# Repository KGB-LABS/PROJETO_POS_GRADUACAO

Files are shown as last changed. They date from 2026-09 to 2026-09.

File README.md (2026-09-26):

# Sistema IoT de Monitoramento Residencial Inteligente com ESP32

## 📌 Concepção e Objetivo do Projeto
Este projeto consiste no desenvolvimento de um sistema embarcado de automação, monitoramento climático e segurança perimetral residencial, fundamentado nas premissas da **Internet das Coisas (IoT)**. Desenvolvido como protótipo funcional para fins acadêmicos de Pós-Graduação, o ecossistema utiliza a placa de desenvolvimento **ESP32 DevKit** como unidade central de processamento para gerenciar, de forma assíncrona, sensores meteorológicos, termo-higrométricos e de intrusão física.

O principal objetivo técnico é garantir a integridade dos dados locais, transmitindo-os de maneira otimizada e segura para plataformas em nuvem, permitindo que o usuário interaja e receba alertas críticos em tempo real, independentemente de sua localização geográfica.

---

## 🏗️ Modelagem e Arquitetura do Sistema 

O fluxo de dados do ecossistema foi estruturado sob o conceito de **comunicação bidirecional**, segregado em três camadas fundamentais (Percepção, Transporte e Aplicação):

```text
  [ CAMADA DE PERCEPÇÃO ]            [ CAMADA DE TRANSPORTE ]            [ CAMADA DE APLICAÇÃO ]
  ┌──────────────────────┐                                               ┌──────────────────────┐
  │  Sensor MH-RD        │ ──┐                                        ┌> │  HiveMQ Cloud (MQTT) │
  │  (Chuva / Digital)   │   │                                        │  └──────────────────────┘
  ├──────────────────────┤   │    ┌─────────────────────────────┐     │
  │  Sensor Magnético    │   ├──> │        ESP32 DevKit         │ ────┤
  │  (Porta / Reed)      │   │    │ - Gestão por Edge Trigger   │     │
  ├──────────────────────┤   │    │ - Portal Cativo Local       │     │  ┌──────────────────────┐
  │  Sensor DHT11        │ ──┘    └─────────────────────────────┘     └> │  Telegram Bot API    │
  │  (Temp. / Umidade)   │                                               └──────────────────────┘
  └──────────────────────┘
```

### 1. Monitoramento Ativo (Modo Publisher / Transmissão Assíncrona)
O sistema opera baseado no princípio de **Gatilho por Borda (Edge Triggering)**. Os sensores de perímetro e meteorológicos são monitorados continuamente na camada de hardware. No entanto, o envio de dados para a nuvem só ocorre quando há uma **transição real de estado físico** (ex: o início/fim de uma chuva ou a abertura/fechamento de uma porta). Essa abordagem de engenharia de software elimina o tráfego de rede redundante, reduzindo o consumo de banda e poupando ciclos de processamento da MCU.

### 2. Requisições Sob Demanda (Modo Subscriber / Interação Remota)
A camada de aplicação permite que o usuário faça consultas ativas ao sistema. Ao enviar um comando de texto estruturado pela interface do usuário, a solicitação é transportada até o microcontrolador, que realiza a leitura imediata dos parâmetros ambientais de temperatura e umidade, retornando as métricas instantaneamente.

---

## 📸 Demonstração Visual do Protótipo

Abaixo está disposto o registro visual da das conexões de Hardware para cada unidade de processamento do ecossistema IoT residencial.

<p align="center">
 
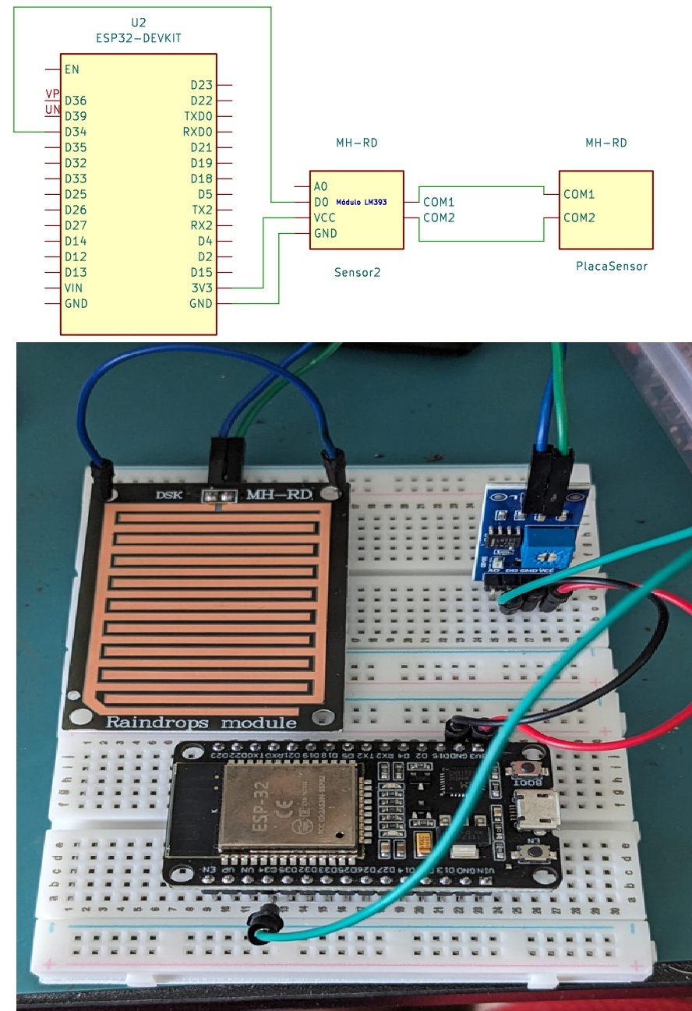
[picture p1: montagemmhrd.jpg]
Placa de Desenvolvimento ESP32 DevKit + Módulo MH-RD
  
  <br>
  <em>Figura 1: Unidade de Processamento Central baseada na placa de desenvolvimento ESP32 DevKit + Módulo MH-RD (CHUVA).</em>
</p>

<p align="center">

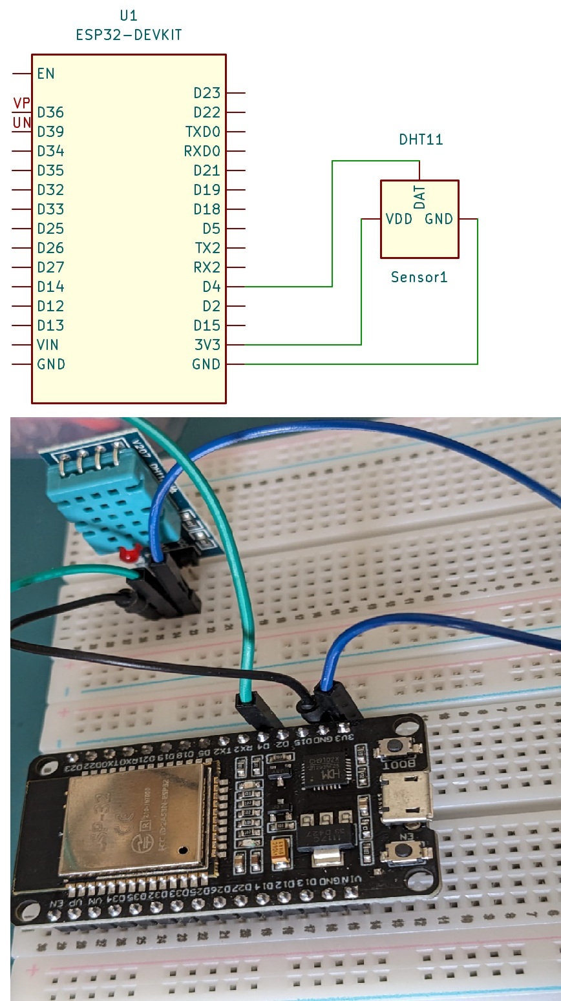
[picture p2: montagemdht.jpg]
Placa de Desenvolvimento ESP32 DevKit + Módulo DHT11
  
  <br>
  <em>Figura 2: Unidade de Processamento Central baseada na placa de desenvolvimento ESP32 DevKit + DHT11 (TEMP).</em>
</p>

<p align="center">

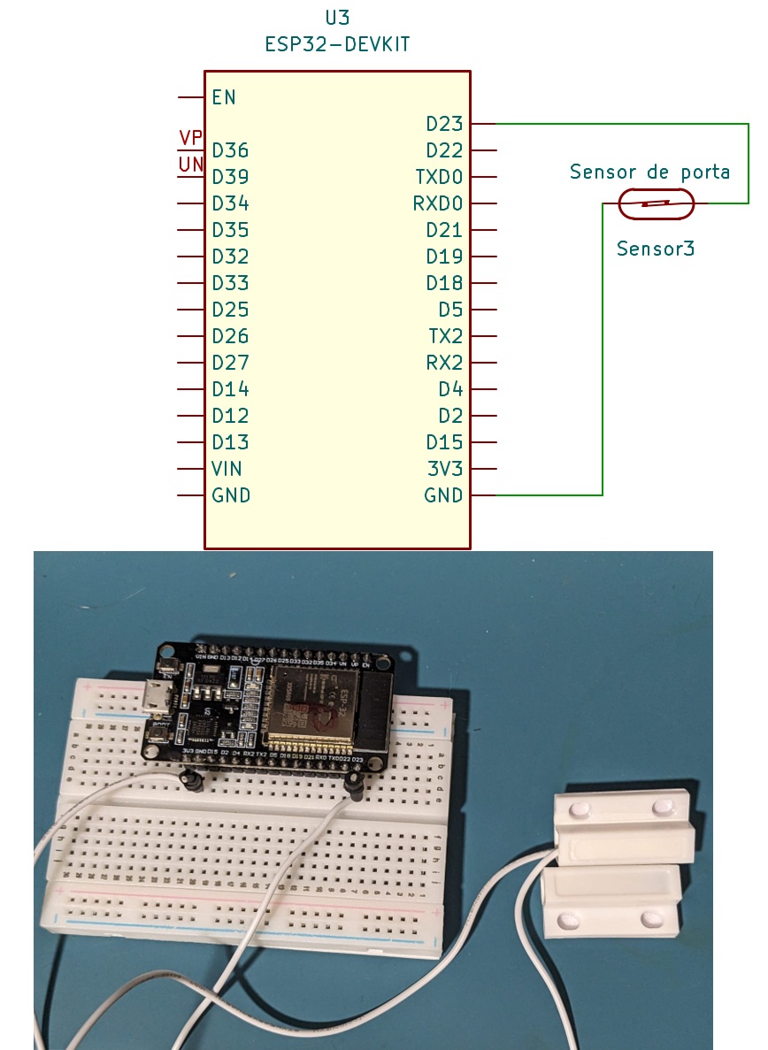
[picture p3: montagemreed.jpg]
Placa de Desenvolvimento ESP32 DevKit + Módulo Reed
  
  <br>
  <em>Figura 3: Unidade de Processamento Central baseada na placa de desenvolvimento ESP32 DevKit + Módulo Reed Sensor de Porta.</em>
</p>

---

## 🛠️ Especificações Técnicas de Hardware

A seleção dos componentes obedeceu a critérios rígidos de estabilidade de sinal, isolamento de ruídos eletromagnéticos e compatibilidade nativa de níveis lógicos em **3.3V DC**:

*   **Unidade de Processamento Central (MCU):** Placa de Desenvolvimento **ESP32 DevKit**. Baseada no SoC Xtensa Dual-Core de 32 bits com clock de até 240 MHz. Integra regulador de tensão onboard para conversão de alimentação USB/Externa para os níveis de barramento internos, além de transceptores para redes sem fio (Wi-Fi 802.11 b/g/n) e subsistema de memória não-volátil (NVS).
<p align="center">
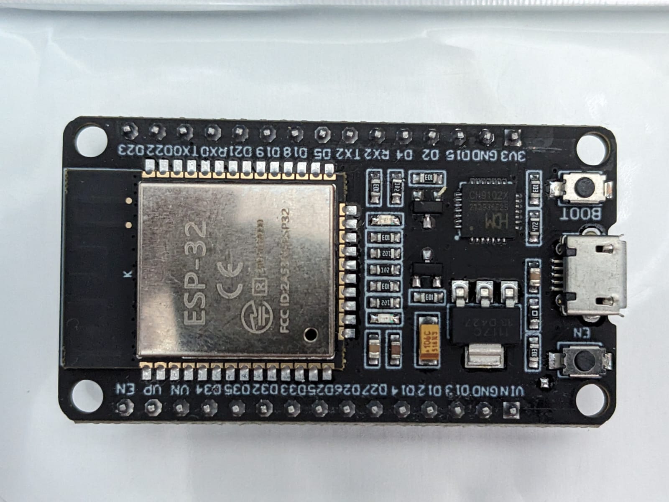
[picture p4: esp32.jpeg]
Esp32 Devkit
  
  <br>
  <em>Figura 4: MCU tipo Esp32 DEVKIT responsável pelo processamento.</em>
</p>

*   **Módulo Sensor Pluviométrico (MH-RD):** Composto por uma grade condutora exposta à precipitação e um circuito integrador baseado no comparador de tensão **LM393**. O módulo filtra as variações resistivas provocadas pela condutividade da água e entrega um sinal digital estabilizado.

<p align="center">
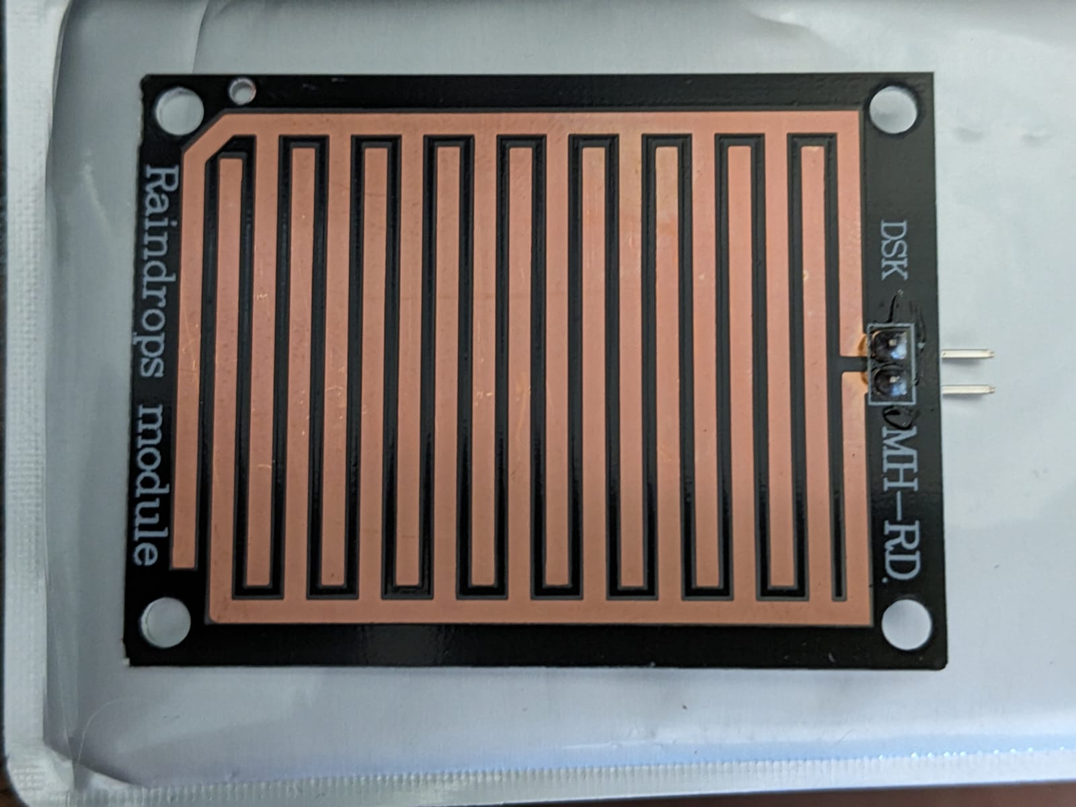
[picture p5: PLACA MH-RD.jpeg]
Placa Sensora de Chuva MH-RD
  
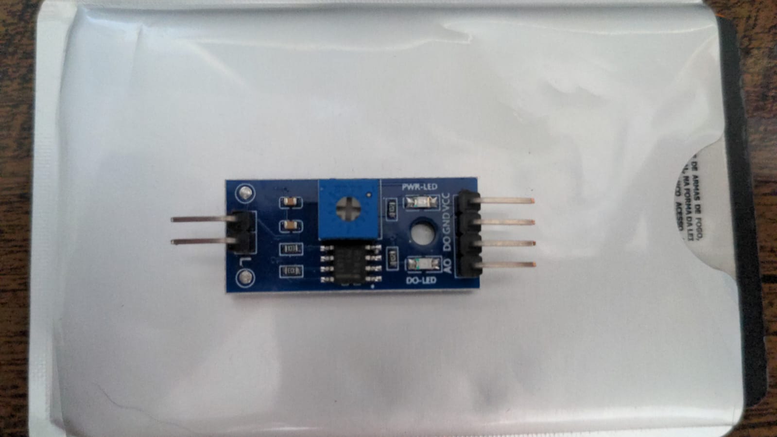
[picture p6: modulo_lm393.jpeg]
Módulo Comparador de Tensão LM393
  
  <br>
  <em>Figura 5: Componentes do sensor de chuva (Esquerda: Placa resistiva MH-RD; Direita: Módulo comparador de sinal LM393).</em>
</p>

*   **Sensor de Intrusão (Porta):** Interruptor magnético MC 38 *Reed Switch* operando como contato aberto/fechado.
<p align="center">
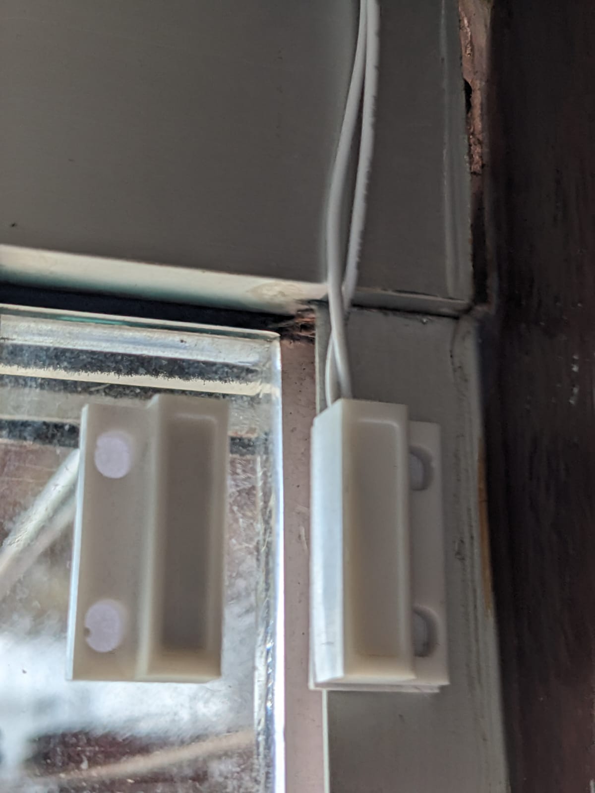
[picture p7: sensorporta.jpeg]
Sensor Porta Reed Switch
  
  <br>
  <em>Figura 6: Sensor MC 38 Reed Switch responsável por informar o estado aberto/fechado de porta.</em>
</p>

*   **Sensor Termo-Higrométrico (DHT11):** Transmissor digital microcontrolado que integra um sensor capacitivo de umidade e um termistor do tipo NTC, convertendo grandezas analógicas em pacotes de dados digitais por meio de protocolo de fio único (*Single-Wire*).

<p align="center">
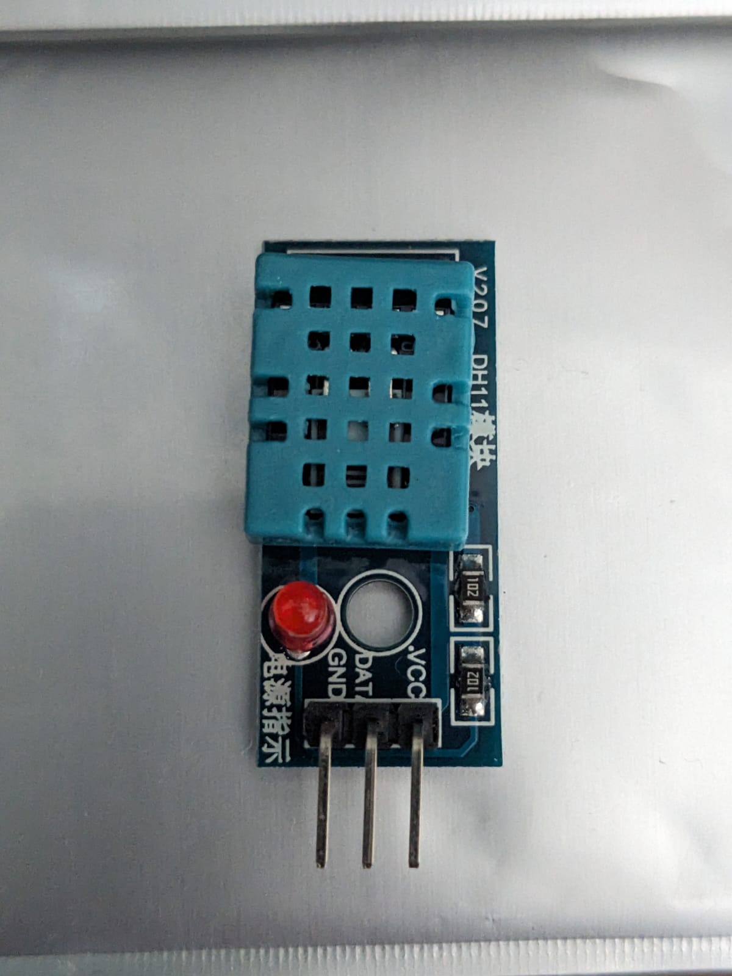
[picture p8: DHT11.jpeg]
Sensor Termo-Higrométrico DHT11
  
  <br>
  <em>Figura 7: Sensor Termo-Higrométrico (DHT11) responsável pela coleta das grandezas de temperatura e umidade.</em>
</p>

### 📌 Justificativa Técnica da Pinagem Escolhida
*   **GPIO 34 (Sensor de Chuva):** Pino físico do barramento do ESP32 DevKit configurado estritamente como entrada de dados (*Input Only*). A escolha baseia-se no fato de pertencer ao barramento interno **ADC1**, o que impede falhas de leitura ou desconexões quando o modem Wi-Fi do chip exige máxima corrente de transmissão (uma limitação física conhecida do barramento secundário ADC2 do ESP32).
*   **GPIO 23 (Sensor de Porta):** Mapeado com o resistor interno de pull-up da arquitetura do chip (`INPUT_PULLUP`). Isso garante que a linha de sinal mantenha-se em nível lógico estável (HIGH) quando o ímã se afasta do sensor, mitigando o efeito de estado flutuante (*floating state*) induzido por ruídos eletromagnéticos externos.
*   **GPIO 0 (Botão BOOT):** Pino nativo de seleção de modo de gravação presente na placa DevKit, reutilizado por software em tempo de execução para atuar como um botão físico de *Factory Reset* das configurações lógicas de rede.

---

## 🌐 Integração, Redes e Protocolos de Comunicação

### 1. Provisionamento de Rede Sem Fio Dinâmico
Para garantir a segurança do sistema e evitar o armazenamento rígido (*hardcoded*) de credenciais de rede domésticas no código-fonte, o sistema implementa um **Gerenciador Dinâmico de Provisionamento**. 
* Caso o dispositivo perca a conectividade ou seja inicializado em um novo ambiente, ele gera autonomamente uma rede local criptografada no modo **Access Point (AP)** com portal cativo HTTP.
* O usuário se conecta a este ponto de acesso via dispositivo móvel para selecionar e salvar de forma segura as novas credenciais de rede diretamente na memória flash do chip.

### 2. Protocolo de Mensagens MQTT via Broker Cloud
O transporte das informações estruturadas de telemetria é feito através do protocolo **MQTT (Message Queuing Telemetry Transport)**, utilizando pacotes leves em formato **JSON**. A comunicação é direcionada por meio de sockets criptografados TLS (porta padrão 8883) para um cluster em nuvem de alta disponibilidade do **HiveMQ Cloud**, organizados sob tópicos hierárquicos. O cliente de rede dispensa a validação estática de cadeias de certificados públicos locais para otimizar o uso da memória RAM (SRAM) do sistema embarcado.

### 3. Interface Homem-Máquina (IHM) com Controle de Acesso
A camada de interação com o usuário final é integrada diretamente à API de mensagem do **Telegram**. Para assegurar a confidencialidade e a integridade da automação residencial, o sistema possui uma diretiva rígida de controle de acesso baseada no identificador numérico único do usuário (*Chat ID*) e Token. Qualquer tentativa de comando ou requisição originada por contas não cadastradas é sumariamente rejeitada pelo microcontrolador, ainda que tenham acessado o bot.

<p align="center">
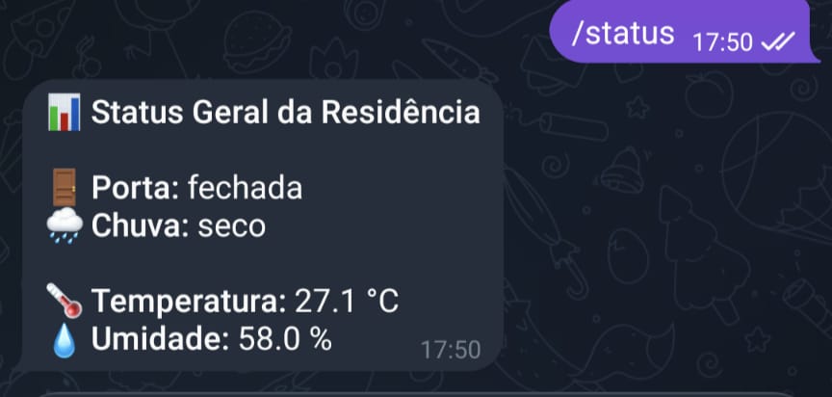
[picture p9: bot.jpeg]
Visão do Bot=
  
  <br>
  <em>Figura 9: Case impresso em 3D.</em>
</p>

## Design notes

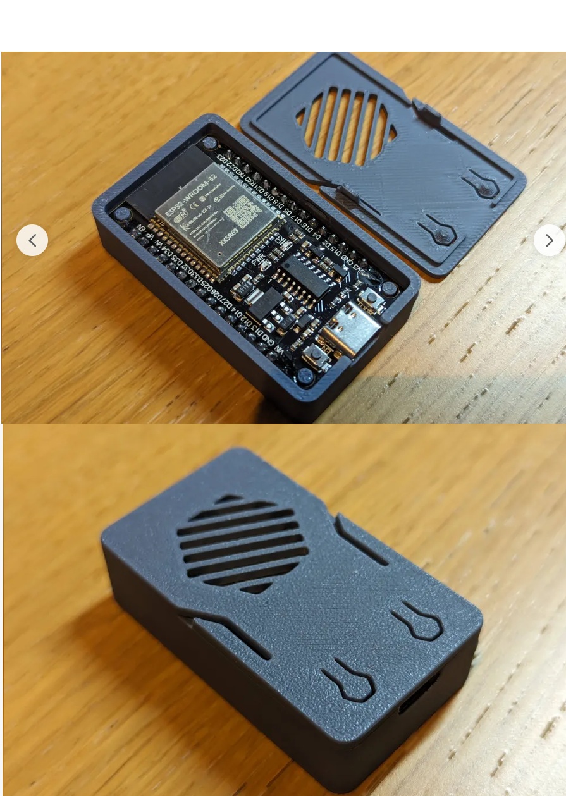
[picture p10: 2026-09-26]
caseesp2.jpg

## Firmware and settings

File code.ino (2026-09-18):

#include <WiFi.h>
#include <WiFiClientSecure.h>
#include <PubSubClient.h>
#include <WiFiManager.h>
#include <UniversalTelegramBot.h>
#include <ArduinoJson.h>
#include <DHT.h>

// --- Definição dos Pinos ---
#define BUTTON_BOOT 0     // Botão BOOT da placa para Reset do Wi-Fi
#define PIN_CHUVA 34      // Pino digital do Sensor de Chuva
#define PIN_PORTA 23      // Pino digital do Sensor de Porta (Magnético)
#define PIN_DHT 4         // Pino do Sensor de Temperatura/Umidade
#define DHTTYPE DHT11     // Mude para DHT22 se estiver usando o DHT22

// --- Configurações do HiveMQ Cloud ---
const char* MQTT_SERVER = "SEUSERVER.s1.eu.hivemq.cloud";
const int MQTT_PORT = 8883;
const char* MQTT_USER = "SEU USUÁRIO";
const char* MQTT_PASSWORD = "SUA SENHA";

// --- Configurações do Telegram ---
#define BOTtoken "SEU TOKEN DO BOT"
#define CHAT_ID "SEU CHAT ID"

// Tópicos MQTT
const char* TOPIC_STATUS = "casa/status";

// Inicialização dos sensores e conexões
DHT dht(PIN_DHT, DHTTYPE);

WiFiClientSecure netClientMQTT;
WiFiClientSecure netClientTelegram;

PubSubClient mqttClient(netClientMQTT);
UniversalTelegramBot bot(BOTtoken, netClientTelegram);

// Variáveis de estado dos sensores
int estadoChuvaAnterior = -1;
int estadoPortaAnterior = -1;

unsigned long ultimoChequeTelegram = 0;
const unsigned long INTERVALO_TELEGRAM = 1000; // Checa novas mensagens a cada 1 segundo

// Função para enviar mensagem ao Telegram e publicar no HiveMQ
void notificar(String mensagem) {
  Serial.println("Notificação: " + mensagem);
  bot.sendMessage(CHAT_ID, mensagem, "Markdown");
  if (mqttClient.connected()) {
    mqttClient.publish(TOPIC_STATUS, mensagem.c_str());
  }
}

// Botão BOOT para resetar as credenciais Wi-Fi (Pressione por 3 segundos)
void checkResetButtonInLoop() {
  if (digitalRead(BUTTON_BOOT) == LOW) {
    Serial.println("\nBotão BOOT pressionado! Segure por 3 segundos para resetar o Wi-Fi...");
    delay(3000);
    if (digitalRead(BUTTON_BOOT) == LOW) {
      Serial.println("Limpando configurações de Wi-Fi...");
      WiFiManager wm;
      wm.resetSettings();
      delay(1000);
      ESP.restart();
    }
  }
}

// Processa mensagens recebidas pelo Bot do Telegram
void handleNewMessages(int numNewMessages) {
  for (int i = 0; i < numNewMessages; i++) {
    String chat_id = String(bot.messages[i].chat_id);
    
    // Responde apenas ao usuário autorizado
    if (chat_id != CHAT_ID) {
      bot.sendMessage(chat_id, "Acesso não autorizado.", "");
      continue;
    }

    String text = bot.messages[i].text;

    if (text == "/termometro" || text == "/termometro@SeuBot") {
      float temp = dht.readTemperature();
      float umi = dht.readHumidity();

      if (isnan(temp) || isnan(umi)) {
        bot.sendMessage(CHAT_ID, "⚠️ Erro ao ler os dados do sensor de temperatura!", "");
      } else {
        // 1. Envia resposta formatada para o Telegram
        String resposta = "🌡️ *Leitura Térmica*\n\n";
        resposta += "Temperatura: " + String(temp, 1) + " °C\n";
        resposta += "Umidade: " + String(umi, 1) + " %";
        bot.sendMessage(CHAT_ID, resposta, "Markdown");

        // 2. Publica os dados de leitura no HiveMQ Cloud
        if (mqttClient.connected()) {
          String payloadMQTT = "{\"temperatura\":" + String(temp, 1) + ",\"umidade\":" + String(umi, 1) + "}";
          mqttClient.publish(TOPIC_STATUS, payloadMQTT.c_str());
          Serial.println("Publicado no HiveMQ: " + payloadMQTT);
        }
      }
    }
  }
}

// Monitora alterações dos sensores de Chuva e Porta
void checarSensores() {
  // Sensor de chuva (LOW indica presença de água no módulo)
  int leituraChuva = digitalRead(PIN_CHUVA);
  if (leituraChuva != estadoChuvaAnterior) {
    estadoChuvaAnterior = leituraChuva;
    if (leituraChuva == LOW) {
      notificar("🌧️ chovendo");
    } else {
      notificar("☀️ sem chuva no momento");
    }
  }

  // Sensor de porta (HIGH = Aberta com pull-up, LOW = Fechada)
  int leituraPorta = digitalRead(PIN_PORTA);
  if (leituraPorta != estadoPortaAnterior) {
    estadoPortaAnterior = leituraPorta;
    if (leituraPorta == HIGH) {
      notificar("🚪 porta aberta");
    } else {
      notificar("🔒 porta fechada");
    }
  }
}

void reconnectMQTT() {
  if (!mqttClient.connected()) {
    Serial.print("Conectando ao HiveMQ...");
    String clientId = "ESP32Client-";
    clientId += String(random(0xffff), HEX);

    if (mqttClient.connect(clientId.c_str(), MQTT_USER, MQTT_PASSWORD)) {
      Serial.println(" Conectado ao HiveMQ!");
    } else {
      Serial.print(" Falha MQTT. Código: ");
      Serial.println(mqttClient.state());
    }
  }
}

void setup() {
  Serial.begin(115200);

  pinMode(BUTTON_BOOT, INPUT_PULLUP);
  pinMode(PIN_CHUVA, INPUT);
  pinMode(PIN_PORTA, INPUT_PULLUP);

  dht.begin();

  WiFiManager wm;
  
  // Verifica reset do Wi-Fi logo na energização
  if (digitalRead(BUTTON_BOOT) == LOW) {
    delay(3000);
    if (digitalRead(BUTTON_BOOT) == LOW) {
      wm.resetSettings();
      ESP.restart();
    }
  }

  wm.setConfigPortalTimeout(180);

  bool res = wm.autoConnect("Controle Residencial", "abcde12345678");
  if (!res) {
    Serial.println("Tempo limite atingido. Reiniciando...");
    ESP.restart();
  }

  Serial.println("Wi-Fi Conectado!");

  netClientMQTT.setInsecure();
  netClientTelegram.setInsecure();

  mqttClient.setServer(MQTT_SERVER, MQTT_PORT);

  reconnectMQTT();
  notificar("🤖 *Sistema de Monitoramento Conectado!*");
}

void loop() {
  // Checa se o usuário quer resetar o Wi-Fi sem instanciar objeto desnecessário
  checkResetButtonInLoop();

  if (WiFi.status() != WL_CONNECTED) {
    WiFi.reconnect();
    delay(5000);
    return;
  }

  reconnectMQTT();
  mqttClient.loop();

  // Monitora alterações dos sensores em tempo real
  checarSensores();

  // Verifica novos comandos no Telegram
  if (millis() - ultimoChequeTelegram > INTERVALO_TELEGRAM) {
    int numNovasMensagens = bot.getUpdates(bot.last_message_received + 1);
    while (numNovasMensagens) {
      handleNewMessages(numNovasMensagens);
      numNovasMensagens = bot.getUpdates(bot.last_message_received + 1);
    }
    ultimoChequeTelegram = millis();
  }
}

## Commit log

2026-09-18 Add project documentation for ESP32 rain monitoring system
    Adiciona documentação detalhada sobre o sistema de monitoramento pluviométrico com ESP32 e sensor MH-RD, incluindo especificações de hardware, implementação do firmware e metodologia de teste.
2026-09-18 Add files via upload
    esquemático do projeto
    [controle_casa.kicad_sch]
2026-09-18 Rename WhatsApp Image 2026-09-18 at 12.44.21(1).jpeg to esp32.jpeg
2026-09-18 Rename WhatsApp Image 2026-09-18 at 12.44.21.jpeg to sensorporta.jpeg
2026-09-26 Update image alt text and add STL file link
